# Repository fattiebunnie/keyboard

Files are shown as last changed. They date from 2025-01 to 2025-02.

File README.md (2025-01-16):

# Keyboard project 

This repo contains packages from different other repos so it will be easier to create a keyboard. 

## Keyboard 65 

65% keyboard

## Reference 

[tmk's keyboard_parts](https://github.com/tmk/keyboard_parts.pretty)

[tmk's kicad_lib](https://github.com/tmk/kicad_lib_tmk)

[egladman's keebs](https://github.com/egladman/keebs.pretty)

[mintexists' whiteboard](https://github.com/mintexists/WhiteBoard/tree/main)

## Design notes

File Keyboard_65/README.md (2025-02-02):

# Design was taken from [WhiteBoard by mintexists](https://github.com/mintexists/WhiteBoard/tree/main)

## Keyboard form factor

This keyboard is a 65% Keyboard with a knob and place for 2 screens to go onto 

### 3D model of the keyboard parts 

#### Top Plate
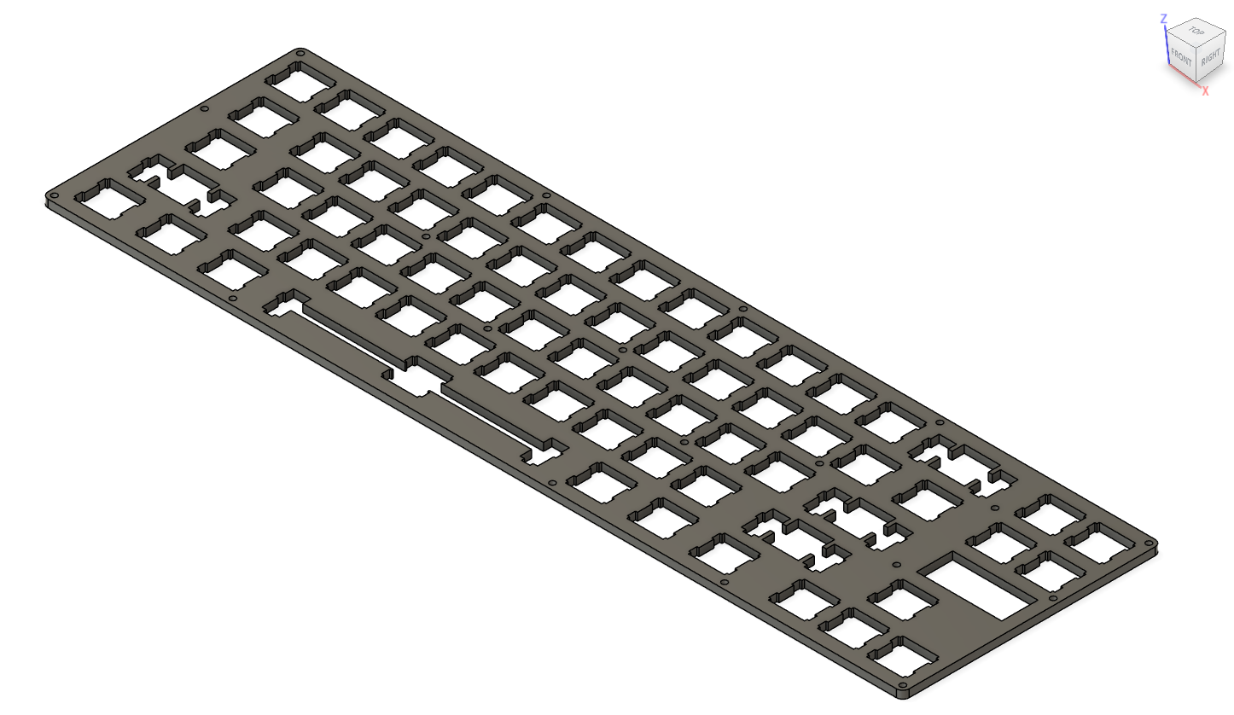
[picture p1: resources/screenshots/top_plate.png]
top_plate

#### Bot Plate
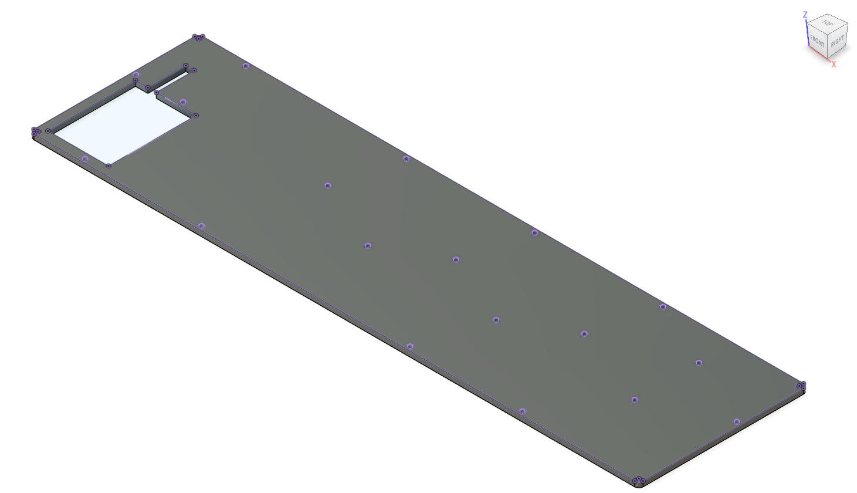
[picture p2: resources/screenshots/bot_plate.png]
bot_plate

#### PCB
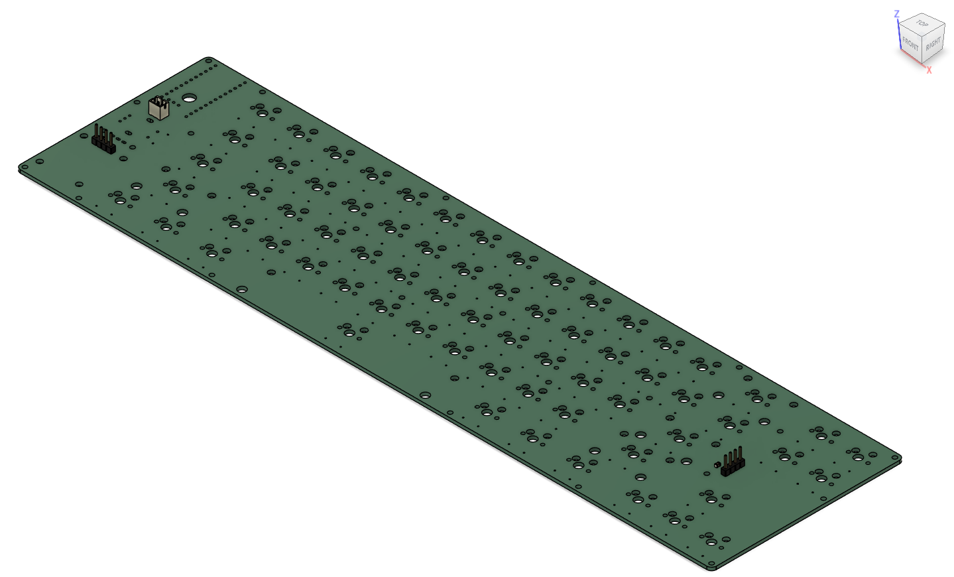
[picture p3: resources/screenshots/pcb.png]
PCB

#### Assembly
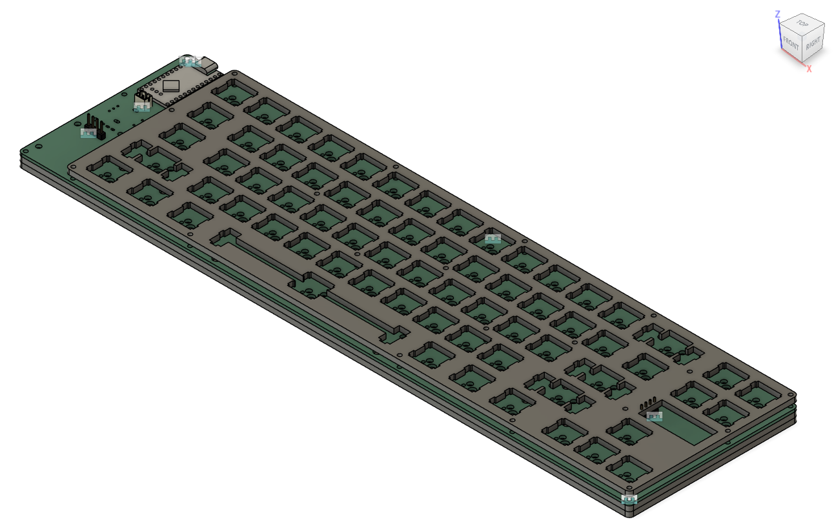
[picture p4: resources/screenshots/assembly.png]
assembly


## Tools

### Kayboard Layout Editor 

[Keyboard layout editor](https://www.keyboard-layout-editor.com/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'&_w:2.25%3B&=Enter%3B&@_w:2.25%3B&=Shift&=Z&=X&=C&=V&=B&=N&=M&=%3C%0A,&=%3E%0A.&=%3F%0A%2F%2F&_w:2.75%3B&=Shift&_x:0.25%3B&=%E2%86%91%3B&@_w:1.25%3B&=Ctrl&_w:1.25%3B&=Win&_w:1.25%3B&=Alt&_a:7&w:6.25%3B&=&_a:4&w:1.25%3B&=Alt&_w:1.25%3B&=Ctrl&_w:1.25%3B&=Menu&_x:0.5%3B&=%E2%86%90&=%E2%86%93&=%E2%86%92) is used for the holes for top plate. Though it may be unnecessary but aesthetics ig.

### Builder

[builder](http://builder.swillkb.com/) for the mounting holes. Copying the layout and adding pasting it into builder gives u the generated mounting holes.

### SVG2ShenZhen

[Badgeek's SVG to ShenZhen](https://github.com/badgeek/svg2shenzhen) makes svg into components in kicad.

### ZMK Firmware

ZMK Firmware was being used because it supported both bluetooth and I2C for display. 

# Complete build

Soldering Job: 

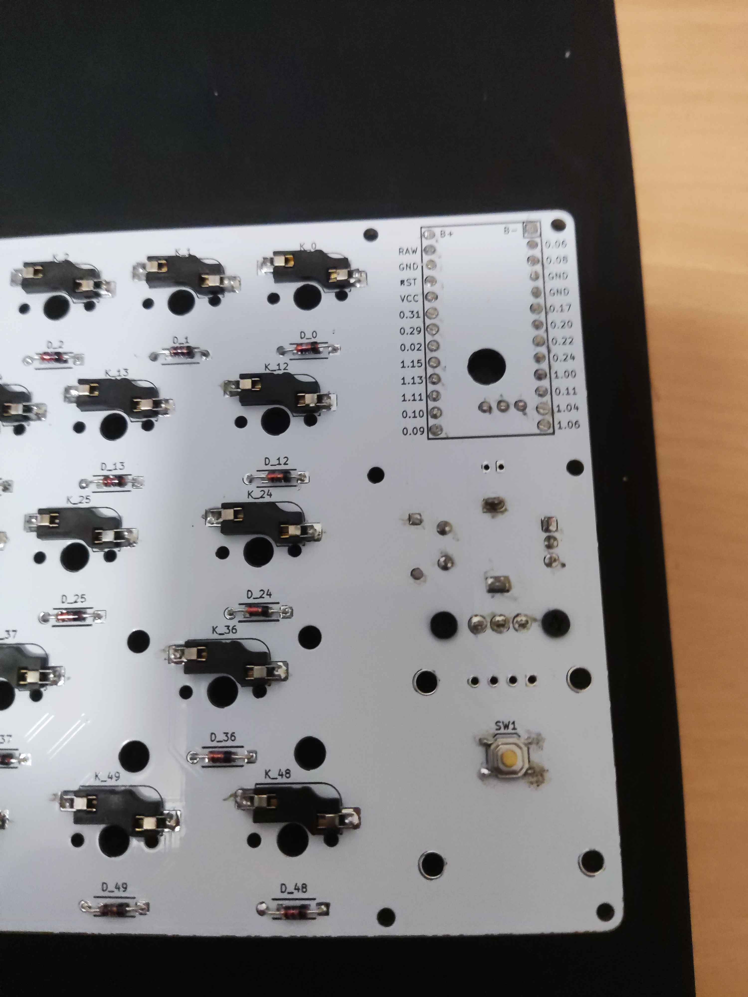
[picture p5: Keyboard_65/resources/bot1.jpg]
bot1


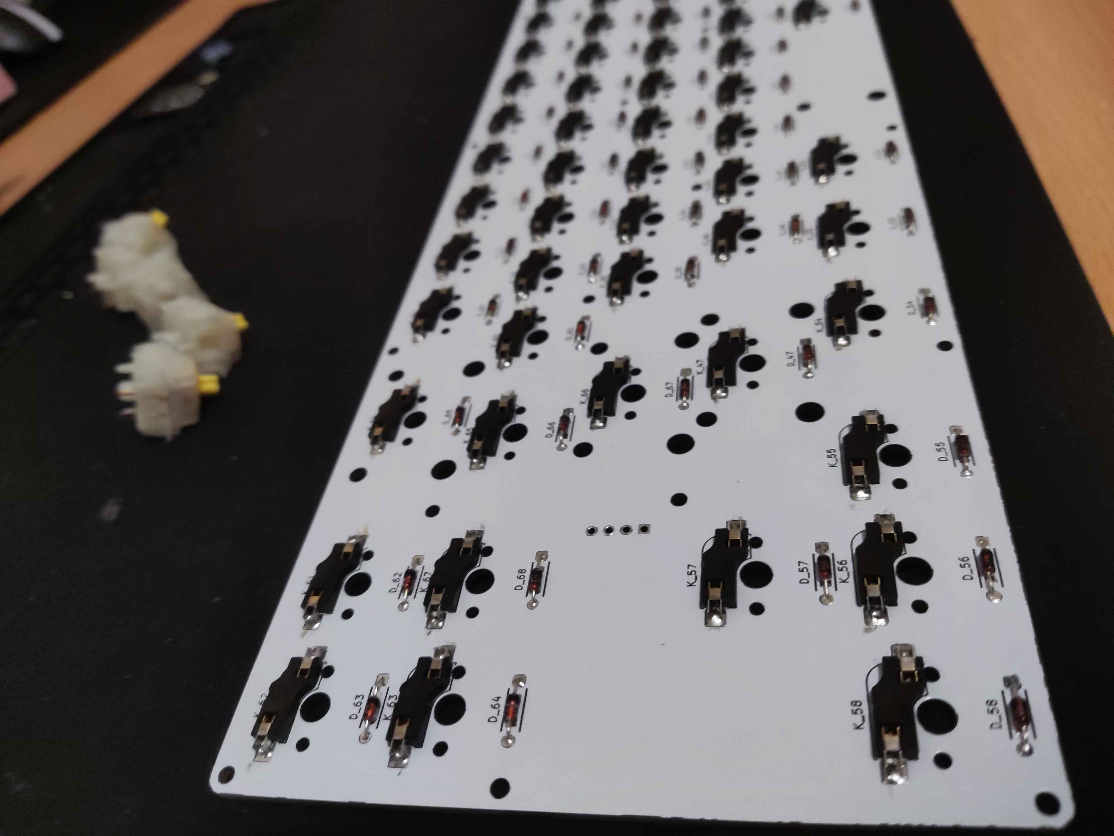
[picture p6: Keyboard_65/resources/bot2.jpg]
bot2


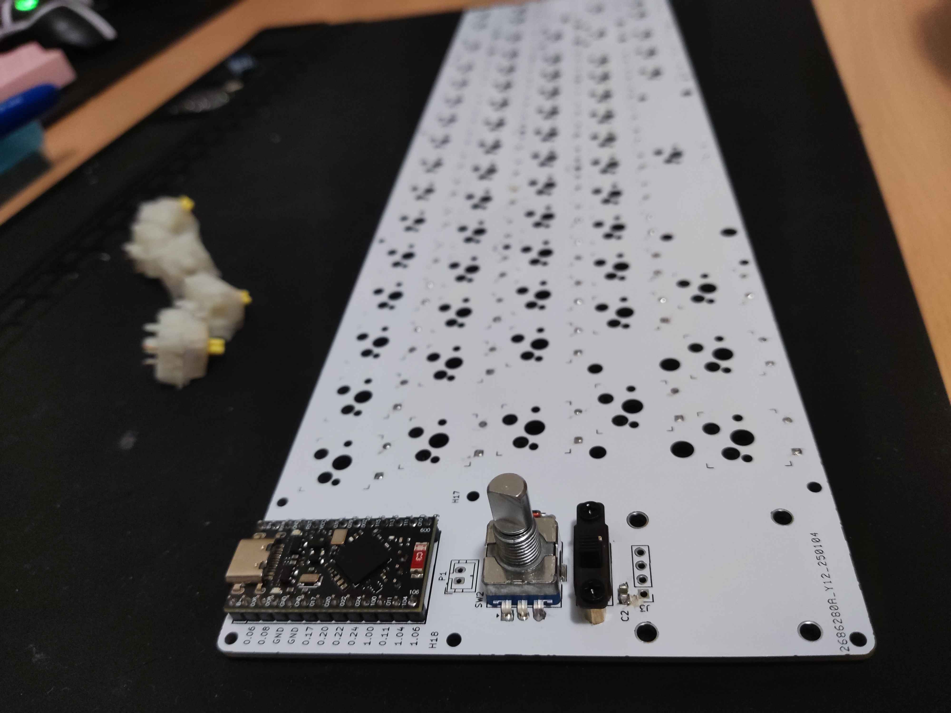
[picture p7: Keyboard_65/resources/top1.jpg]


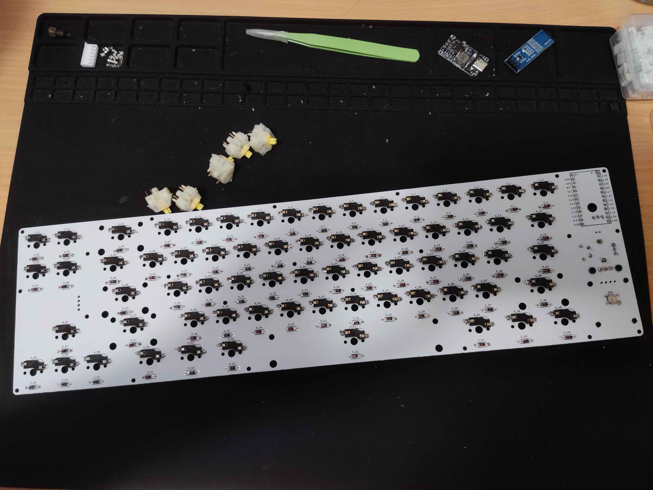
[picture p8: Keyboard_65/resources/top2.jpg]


I soldered the pins and then snipped the excess pins off together with some solder so it is as flush as possible and does not leave excess pointy edges that will end up scratching the user (possibly just me idk) in the future.

Build:

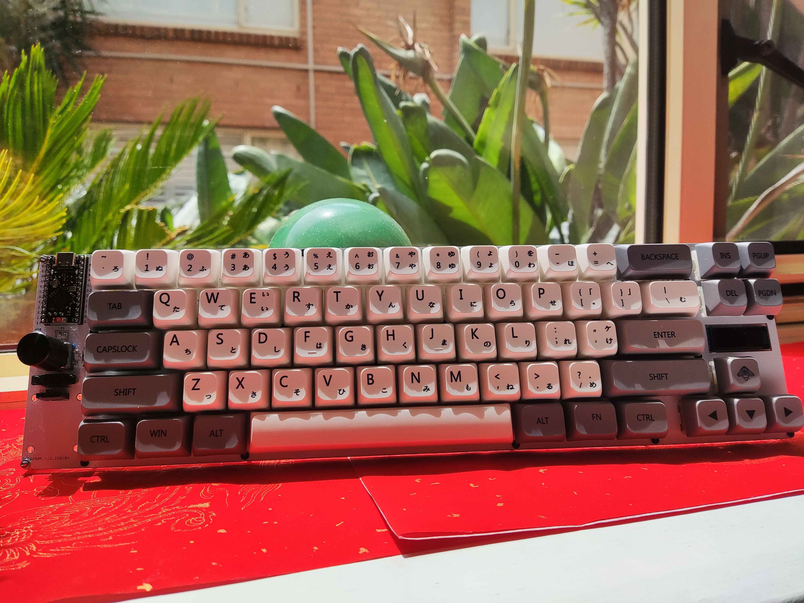
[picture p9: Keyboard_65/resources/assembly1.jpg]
assembly1


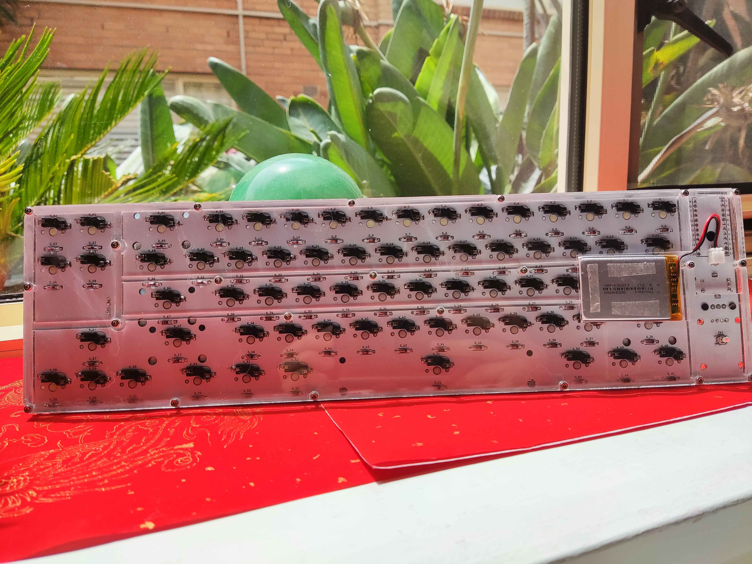
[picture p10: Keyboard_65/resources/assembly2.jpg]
assembly2


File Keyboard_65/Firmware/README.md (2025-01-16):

# Firmware

ZMK for bluetooth + battery management.

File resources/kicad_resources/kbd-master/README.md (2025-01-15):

# KBD - for building keyboard libraries

## KiCad Footprint Libraries

This repository contains the KiCad footprint libraries for building keyboard.

**The libraries in this repository are intended to be used with KiCad version 5 or with a nightly that supports rounded rectangle and polygon pads.**

Each footprint library is stored as a directory with the `.pretty` suffix. The footprint files are `.kicad_mod` files within 

## KiCad Symbols

This repository contains the KiCad schematic symbol libraries for building keyboard.

**The libraries in this repositiory are intended for KiCad version 5.x**

Each symbol library is stored as a `.lib` and `.dcm` file pair.

## KiCad 3D Models
This repository contains 3D models for rendering and MCAD integration, for use with [KiCAD EDA](http://kicad-pcb.org/) software.
The model needs a mechanical model source (a manually-modelled or script-generated file); its WRL counterpart file must be obtained as a conversion from the MCAD model

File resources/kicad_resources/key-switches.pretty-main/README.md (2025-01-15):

# Key Switches

[:globe_with_meridians:中文](/readme_zh-TW.md)

This is a [KiCad](https://www.kicad.org/) footprint library of mechanical keyboard switches, released under the [CERN-OHL-P v2](/LICENSE).

## Usage

It is recommended to use this library with [KiCAD KLE Placer](https://github.com/zykrah/kicad-kle-placer) or [kicad-kbplacer](https://github.com/adamws/kicad-kbplacer) for automatic switch placement.

If you're using Git, you can include this library as a [submodule](https://git-scm.com/docs/git-submodule) via `git submodule add https://github.com/siderakb/key-switches.pretty.git`

Keyboards created using this library: [ErgoSNM](https://github.com/siderakb/ergo-snm-keyboard), [Calcite](https://github.com/siderakb/calcite), [MS60](https://github.com/siderakb/ms60).

## Compatibility Table

| Preview [^preview] | Footprint [^sw-prefix] | Cherry MX | Cherry MX Low Profile | TTC KS32 |  Kailh Choc V1 [^k-choc1] |  Kailh Choc V2 [^k-choc2]  | Gateron Low Profile [^g-lp] | THT [^tht] | Hot-Swap | *nSilk* variants [^ns-suffix] | *swap* variants [^swap-suffix] |
| :---: | --- | :---: | :---: | :---: | :---: | :---: | :---: | :---: | :---: | :---: | :---: |
|  | MX_THT | :white_check_mark: | | | | | | :white_check_mark: | | :white_check_mark: | |
|  | MX_HotSwap_THT | :white_check_mark: | | | | | | :white_check_mark: | :white_check_mark: | :white_check_mark: | |
|  | MX_HotSwap_THT_double | :white_check_mark: | | | | | | :white_check_mark: | :white_check_mark: | | |
|  | MX_HotSwap_THT_double_alt1 | :white_check_mark: | | | | | | :white_check_mark: | :white_check_mark: | | |
|  | MX_HotSwap_THT_double_alt2 | :white_check_mark: | | | | | | :white_check_mark: | :white_check_mark: | | |
|  | MX_HotSwap_PTH | :white_check_mark: | | | | | | :bulb: [^pth] | :white_check_mark: | :white_check_mark: | :white_check_mark: |
|  | MX_HotSwap_PTH_double | :white_check_mark: | | | | | | :bulb: [^pth] | :white_check_mark: | | |
|  | MX_LowProfile_THT | |  :white_check_mark: | :bulb: [^t-ks_vs_c-mxlp] | | | | :white_check_mark: | | :white_check_mark: | |
|  | Gateron_LowProfile_THT | | | | | | :white_check_mark: | :white_check_mark: | | | |
|  | Gateron_LowProfile_HotSwap_THT | | | | | | :white_check_mark: | :white_check_mark: | :white_check_mark: | | |
|  | Gateron_LowProfile_HotSwap_PTH | | | | | | :white_check_mark: | :bulb: [^pth] | :white_check_mark: | | |
|  | Kailh_Choc_V1_THT | | | | :white_check_mark: | | | :white_check_mark: | | :white_check_mark: | :white_check_mark: |
|  | Kailh_Choc_V1_THT_alt1 | | | | :white_check_mark: | | | :white_check_mark: | | | |
|  | Kailh_Choc_V1_HotSwap | | | | :white_check_mark: | | | | :white_check_mark: | :white_check_mark: | |
|  | Kailh_Choc_V1_HotSwap_THT | | | | :white_check_mark: | | | :white_check_mark: | :white_check_mark: | | |
|  | Kailh_Choc_V1_HotSwap_PTH | | | | :white_check_mark: | | | :bulb: [^pth] | :white_check_mark: | | |
|  | Kailh_Choc_V2_THT | | | | | :white_check_mark: | | :white_check_mark: | | :white_check_mark: | |
|  | Kailh_Choc_V1V2_THT_Hybrid | | | | :bulb:[^k-choc1_vs_k-choc2] | :white_check_mark: | | :white_check_mark: | | | |
|  | MX_Kailh_Choc_V1V2_THT_Hybrid | :bulb: [^c-mx_vs_k-choc2] | | | :bulb:[^k-choc1_vs_k-choc2] | :white_check_mark: | | :white_check_mark: | | | |
|  | MX_LowProfile_Kailh_Choc_V1V2_THT_Hybrid | |  :white_check_mark: | :bulb: [^t-ks_vs_c-mxlp] | :bulb:[^k-choc1_vs_k-choc2] | :bulb:[^k-choc2_vs_c-mxlp] | | :white_check_mark: | | | |

> :white_check_mark:: Compatible; :bulb:: Conditionally compatible; Blank: Not compatible.

[^preview]: Preview images are for reference only and may not be updated with the footprints.
[^tht]: THT means through-hole soldering.
[^pth]: PTH means the holes of the Hot-Swap socket are plated, and the switches can be soldered directly without using a socket. However, the soldering difficulty is higher compared to the standard THT edition.
[^k-choc1]: Kailh Choc V1 also known as PG1350.
[^k-choc2]: Kailh Choc V2 also known as PG1353.
[^g-lp]: Gateron Low Profile 1.0 (aka KS-27) and 2.0 (aka KS-33) footprint are compatible.
[^t-ks_vs_c-mxlp]: TTC KS32 and Cherry MX Low Profile are very similar, basically compatible.
[^k-choc1_vs_k-choc2]: The center fix pin of Choc V1 is smaller than Choc V2, however Choc V1 has two additional fix pins ensuring its stability.
[^k-choc2_vs_c-mxlp]: The center fix pin of Choc V2 is smaller than Cherry MX Low Profile, Choc V2 may not be securely fastened.
[^c-mx_vs_k-choc2]: The center fix pin of Cherry MX is smaller than Choc V2, however some Cherry MX has two additional fix pins ensuring its stability.
[^sw-prefix]: Omit the "SW" prefix from the footprint name.
[^ns-suffix]: The footprint with "nSilk" suffix means no top layer silkscreen.
[^swap-suffix]: The footprint with "swap" suffix means the pin number swap.

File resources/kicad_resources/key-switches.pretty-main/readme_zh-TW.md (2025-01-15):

# Key Switches

[:globe_with_meridians:English](/README.md)

此為機械鍵盤鍵軸的 [KiCad](https://www.kicad.org/) Footprint 庫，以 [CERN-OHL-P v2 授權許可](/LICENSE)發佈。

## 用法

建議搭配 [KiCAD KLE Placer](https://github.com/zykrah/kicad-kle-placer) 或 [kicad-kbplacer](https://github.com/adamws/kicad-kbplacer) 使用本庫，以自動擺放鍵軸。

如果你在使用 Git，你可以將本庫作爲 [submodule](https://git-scm.com/docs/git-submodule) 使用，指令爲：`git submodule add https://github.com/siderakb/key-switches.pretty.git`

使用本庫所製作的鍵盤：[ErgoSNM](https://github.com/siderakb/ergo-snm-keyboard)、[Calcite](https://github.com/siderakb/calcite)、[MS60](https://github.com/siderakb/ms60)。

## 兼容表

| 預覽 [^preview] | Footprint [^sw-prefix] | Cherry MX | Cherry MX Low Profile | TTC KS32 |  Kailh Choc V1 [^k-choc1] |  Kailh Choc V2 [^k-choc2]  | Gateron Low Profile [^g-lp] | THT [^tht] | 熱插拔 | *nSilk* 變體 [^ns-suffix] | *swap* 變體 [^swap-suffix] |
| :---: | --- | :---: | :---: | :---: | :---: | :---: | :---: | :---: | :---: | :---: | :---: |
|  | MX_THT | :white_check_mark: | | | | | | :white_check_mark: | | :white_check_mark: | |
|  | MX_HotSwap_THT | :white_check_mark: | | | | | | :white_check_mark: | :white_check_mark: | :white_check_mark: | |
|  | MX_HotSwap_THT_double | :white_check_mark: | | | | | | :white_check_mark: | :white_check_mark: | | |
|  | MX_HotSwap_THT_double_alt1 | :white_check_mark: | | | | | | :white_check_mark: | :white_check_mark: | | |
|  | MX_HotSwap_THT_double_alt2 | :white_check_mark: | | | | | | :white_check_mark: | :white_check_mark: | | |
|  | MX_HotSwap_PTH | :white_check_mark: | | | | | | :bulb: [^pth] | :white_check_mark: | :white_check_mark: | :white_check_mark: |
|  | MX_HotSwap_PTH_double | :white_check_mark: | | | | | | :bulb: [^pth] | :white_check_mark: | | |
|  | MX_LowProfile_THT | |  :white_check_mark: | :bulb: [^t-ks_vs_c-mxlp] | | | | :white_check_mark: | | :white_check_mark: | |
|  | Gateron_LowProfile_THT | | | | | | :white_check_mark: | :white_check_mark: | | | |
|  | Gateron_LowProfile_HotSwap_THT | | | | | | :white_check_mark: | :white_check_mark: | :white_check_mark: | | |
|  | Gateron_LowProfile_HotSwap_PTH | | | | | | :white_check_mark: | :bulb: [^pth] | :white_check_mark: | | |
|  | Kailh_Choc_V1_THT | | | | :white_check_mark: | | | :white_check_mark: | | :white_check_mark: | :white_check_mark: |
|  | Kailh_Choc_V1_THT_alt1 | | | | :white_check_mark: | | | :white_check_mark: | | | |
|  | Kailh_Choc_V1_HotSwap | | | | :white_check_mark: | | | | :white_check_mark: | :white_check_mark: | |
|  | Kailh_Choc_V1_HotSwap_THT | | | | :white_check_mark: | | | :white_check_mark: | :white_check_mark: | | |
|  | Kailh_Choc_V1_HotSwap_PTH | | | | :white_check_mark: | | | :bulb: [^pth] | :white_check_mark: | | |
|  | Kailh_Choc_V2_THT | | | | | :white_check_mark: | | :white_check_mark: | | :white_check_mark: | |
|  | Kailh_Choc_V1V2_THT_Hybrid | | | | :bulb:[^k-choc1_vs_k-choc2] | :white_check_mark: | | :white_check_mark: | | | |
|  | MX_Kailh_Choc_V1V2_THT_Hybrid | :bulb: [^c-mx_vs_k-choc2] | | | :bulb:[^k-choc1_vs_k-choc2] | :white_check_mark: | | :white_check_mark: | | | |
|  | MX_LowProfile_Kailh_Choc_V1V2_THT_Hybrid | |  :white_check_mark: | :bulb: [^t-ks_vs_c-mxlp] | :bulb:[^k-choc1_vs_k-choc2] | :bulb:[^k-choc2_vs_c-mxlp] | | :white_check_mark: | | | |

> :white_check_mark:: 兼容; :bulb:: 有條件的兼容; 空白: 不兼容.

[^preview]: 預覽圖片僅供參考，不一定會隨 Footprint 更新。
[^tht]: THT 代表通孔焊接。
[^pth]: PTH 代表熱插拔座的孔壁有電鍍，鍵軸也可以在無熱插拔座的情況下直接焊接，但是其焊接難度會比標準 THT 版本更高。
[^k-choc1]: Kailh Choc V1 也稱為 PG1350。
[^k-choc2]: Kailh Choc V2 也稱為 PG1353。
[^g-lp]: Gateron Low Profile  1.0（又名 KS-27）與 2.0（又名 KS-33）的 Footprint 互相兼容。
[^t-ks_vs_c-mxlp]: TTC KS32 與 Cherry MX Low Profile 非常相似，基本上兼容。
[^k-choc1_vs_k-choc2]: Choc V1 的中央固定銷比 Choc V2 還小，但是 Choc V1 有另外兩個固定銷，所以足夠穩定。
[^k-choc2_vs_c-mxlp]: Choc V2 的中央固定銷比 Cherry MX Low Profile 還小，Choc V2 可能無法固定得很穩。
[^c-mx_vs_k-choc2]: Cherry MX 的中央固定銷比 Choc V2 還小，但是有些 Cherry MX 有另外兩個固定銷，所以足夠穩定。
[^sw-prefix]: 省略 Footprint 名稱中的 "SW" 前綴。
[^ns-suffix]: 帶有 "nSilk" 後綴的 Footprint 代表沒有頂層絲印。
[^swap-suffix]: 帶有 "swap" 後綴的 Footprint 代表接腳編號互換。

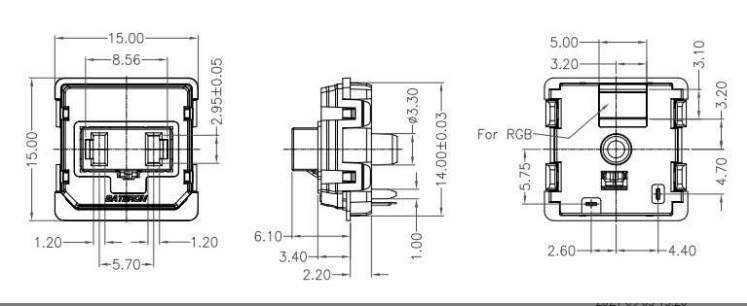
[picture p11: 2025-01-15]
resources/documentations/d513c566a904f95f54a6149d5275fb9d.jpg

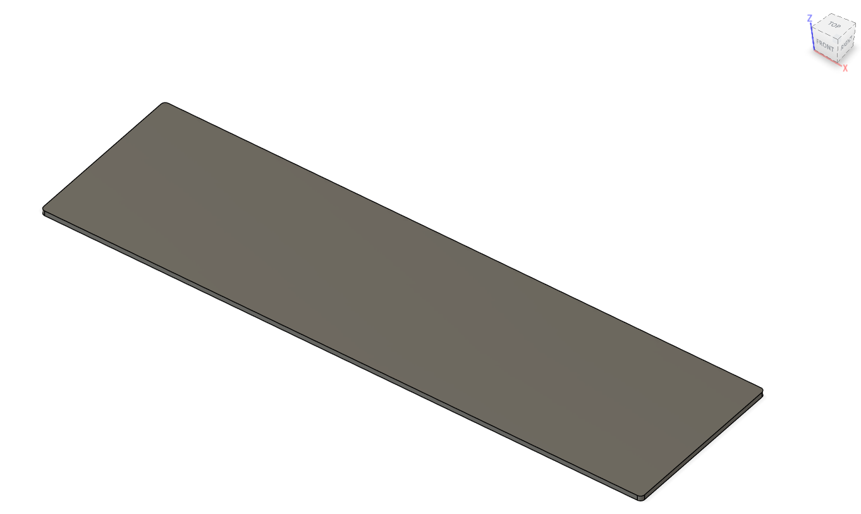
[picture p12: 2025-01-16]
resources/screenshots/bot.png

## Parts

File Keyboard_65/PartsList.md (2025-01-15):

# Parts List

| Name | Count | Comment | Cost | Recommended |
|---|---|---|---|---|
| PCB | 1 | Many sites have minimum order quantities larger then 1 | $14.30 | JLCPCB |
| Plate | 1 | Many sites have minimum order quantities larger then 1 | $30.00 | JLCPCB |
| Bottom Plate | 1 | Many sites have minimum order quantities larger then 1 | $15.80 | JLCPCB |
| Pro Micro Compatible Microcontroller | 1 | I recommend the Elite-C by Keebio **Make sure you order a set with header pins if you are not using a socket** | $18 | https://keeb.io/products/elite-c-low-profile-version-usb-c-pro-micro-replacement-atmega32u4 |
| Diodes | 60 | Get more to be safe | $2.99 | https://keeb.io/products/1n4148-diodes |
| Hot Swap Sockets | 60 | Get more to be safe | $10 for 100 | https://kbdfans.com/products/mechanical-keyboard-switches-kailh-pcb-socket |
| M2 Screws | 100 | This is more then needed but good to be safe | | |
| M2 Standoffs | | Needs to be heights with a difference of 5mm, for example 5mm and 10mm or 3mm and 8mm<br>(Make sure the screws aren't too long in case of short standoffs) | | |
| Rotary Encoder | 1 | Make sure this is high quality as low quality encoders can have issues | $2 | https://keeb.io/products/rotary-encoder-ec11 |
| Encoder Knob | 1 | You can find cheaper knobs on Keebio but I prefer these | $15.99 | https://www.amazon.com/dp/B071DTQ2WN |
| Switches | 60 | | | |
| Keycaps | 60 | I recommend a set of uniform profile keycaps or a set of keycaps compatible with the Preonic | | |
| Plate Mount 2u Stabilizer | 1 | Currently this is not compatible with PCB mount stabilizers but this can be fixed if needed | | |
| (Optional) Microcontroller Sockets | 1 | Use these if you want the ability to change out what microcontroller you use | $4-$10 | |
| (Optional) 6mm Tactile Button | 1 | This is used as a reset button | | |
| (Optional) Braided USB Cable | 1 | Recommending Donut Cables here because they helped me out with learning some PCB design (I was not paid to say this) | $10-$20 | https://donutcables.com/ |

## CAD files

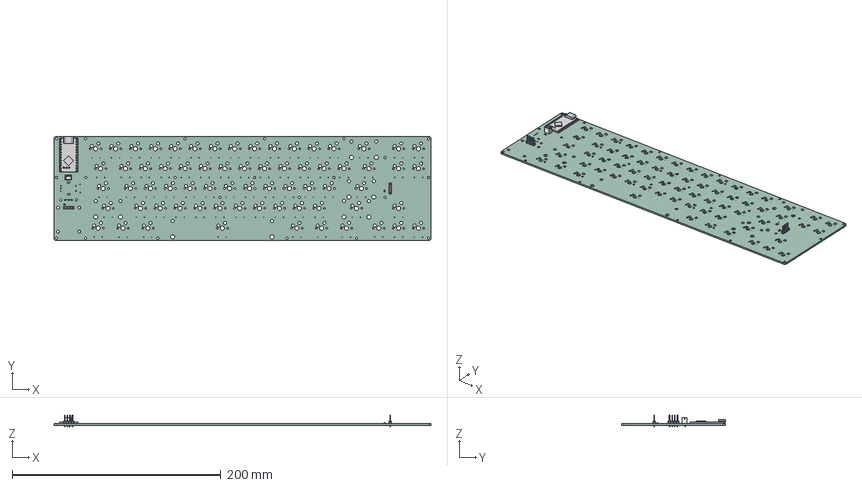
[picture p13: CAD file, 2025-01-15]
Keyboard_65/Kicad Files/Mainpcb.step
361.6 x 100.2 x 11.9 mm
JST_B2B_PH_K
C_0805_2012Metric x 2
nrf54840-ProMicro v2
PinHeader_1x04_P254mm_Vertical x 2
Mainpcb_PCB

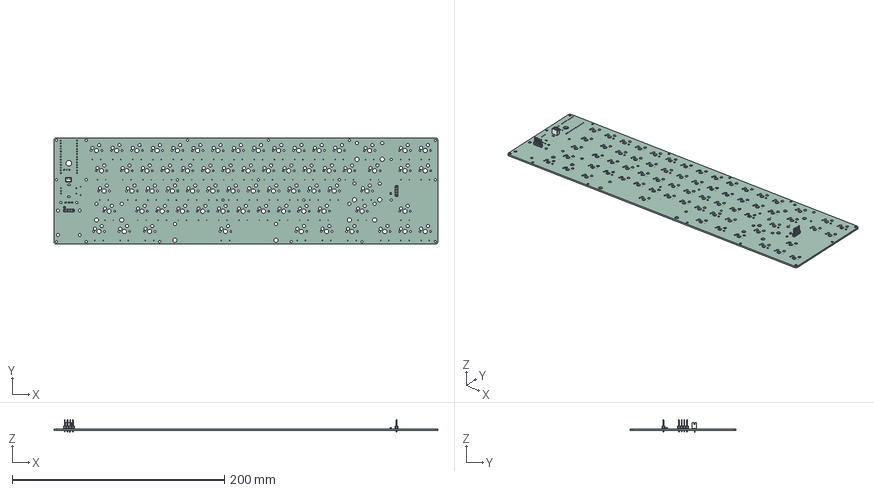
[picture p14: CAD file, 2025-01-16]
resources/3DModels/Mainpcb v2.step
361.6 x 100.2 x 11.9 mm
JST_B2B_PH_K
C_0805_2012Metric_1 x 2
PinHeader_1x04_P254mm_Vertical x 2
Mainpcb_PCB

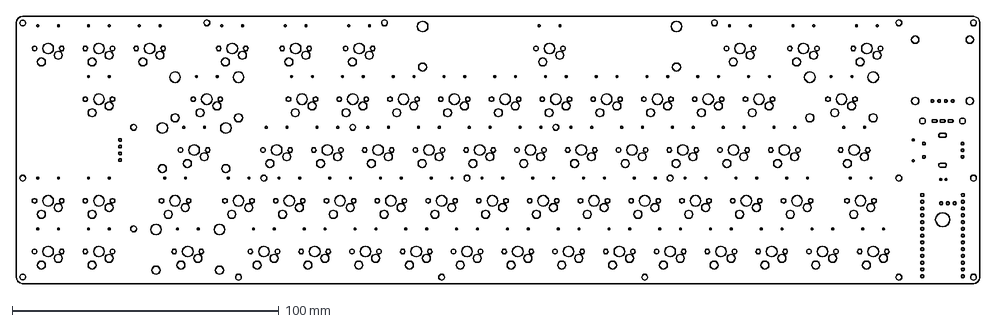
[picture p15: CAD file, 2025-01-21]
Keyboard_65/kb_layout.dxf
361.6 x 100.2 mm

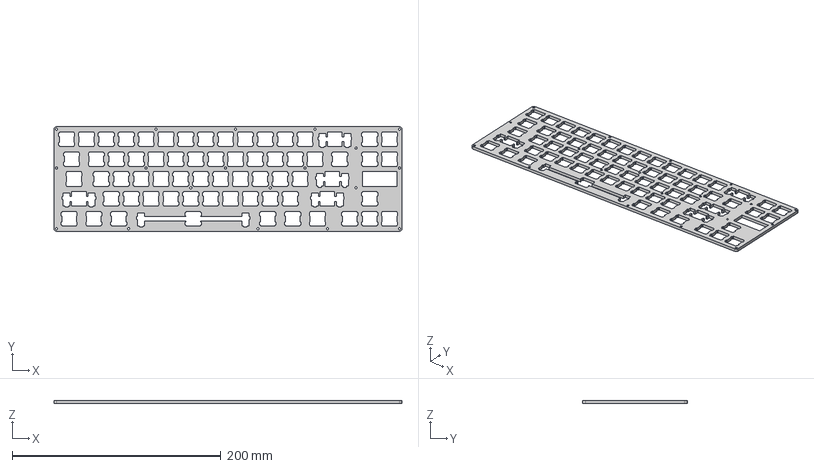
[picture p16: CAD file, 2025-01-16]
resources/3DModels/top_layout v3.step
333.6 x 100.2 x 3.00 mm

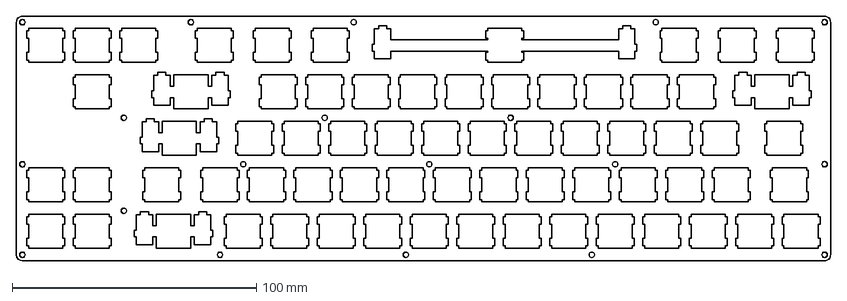
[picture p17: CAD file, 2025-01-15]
resources/misc/top_v2.dxf
333.6 x 100.2 mm

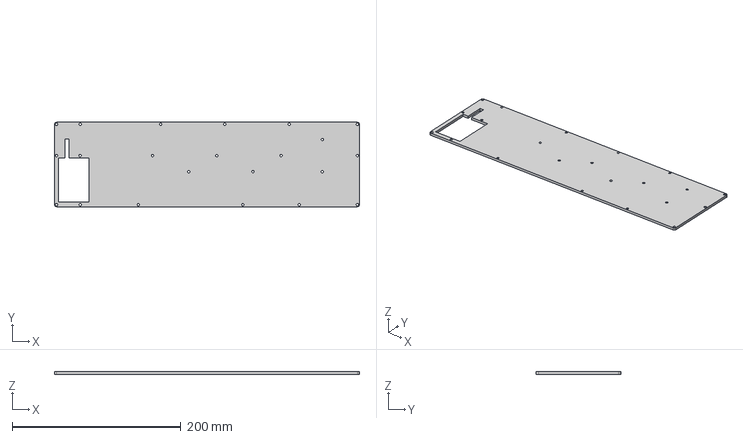
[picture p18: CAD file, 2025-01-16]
resources/3DModels/kb_bot_plate v4.step
361.6 x 100.2 x 3.00 mm

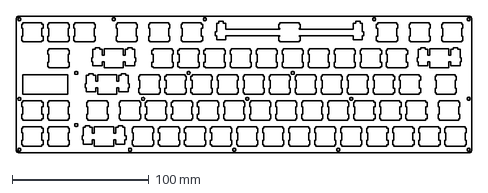
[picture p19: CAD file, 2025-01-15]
resources/misc/top_plate_v2.dxf
333.6 x 100.2 mm

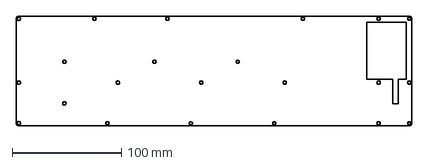
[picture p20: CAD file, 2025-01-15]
resources/misc/bot_plate.dxf
361.6 x 100.2 mm

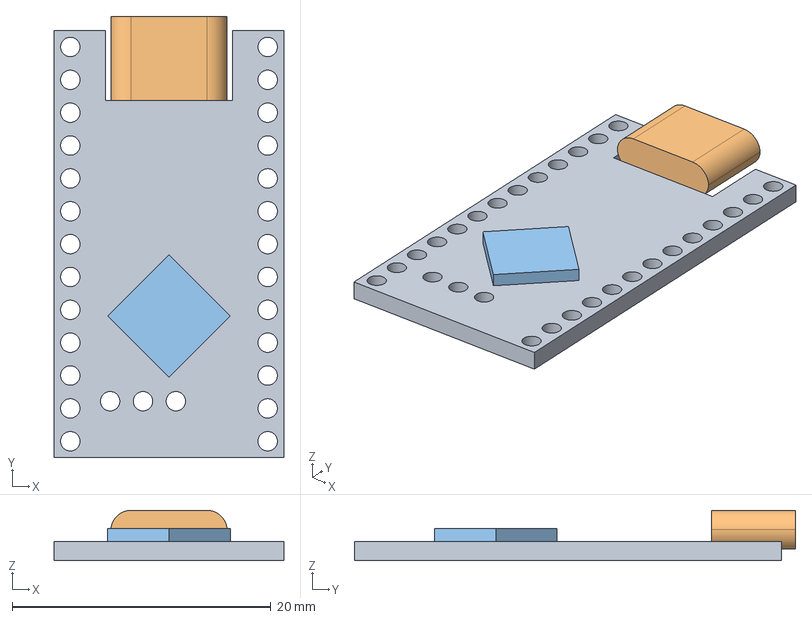
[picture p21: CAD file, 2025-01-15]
resources/3DModels/nrf54840-ProMicro.step
17.8 x 34.1 x 3.90 mm
board
usbc_port
mcu

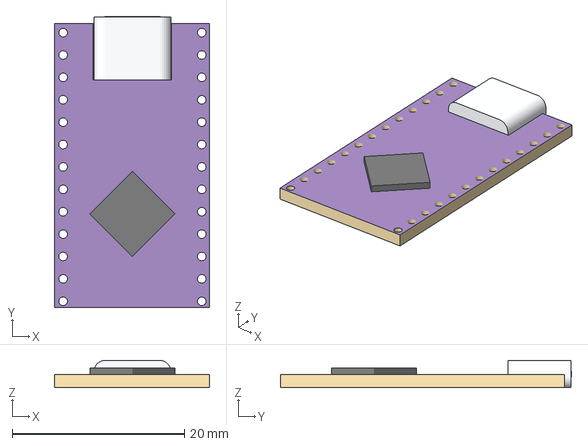
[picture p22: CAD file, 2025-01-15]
resources/3DModels/nRF52840 Reference.3mf
18.0 x 33.9 x 3.15 mm

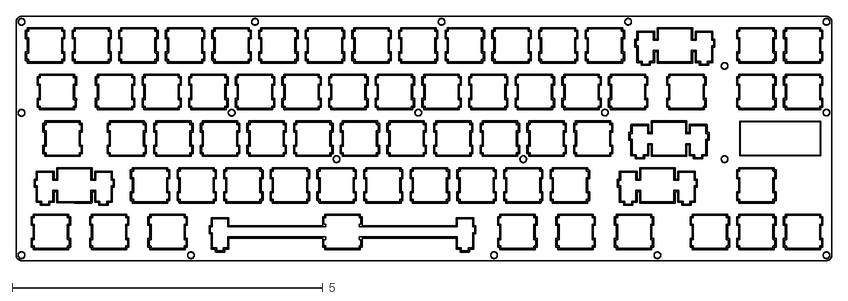
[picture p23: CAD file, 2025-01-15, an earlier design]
Keyboard_65/Kicad Files/Gerbers/archive/Top3/top-F_Cu.dxf
13.1 x 3.93

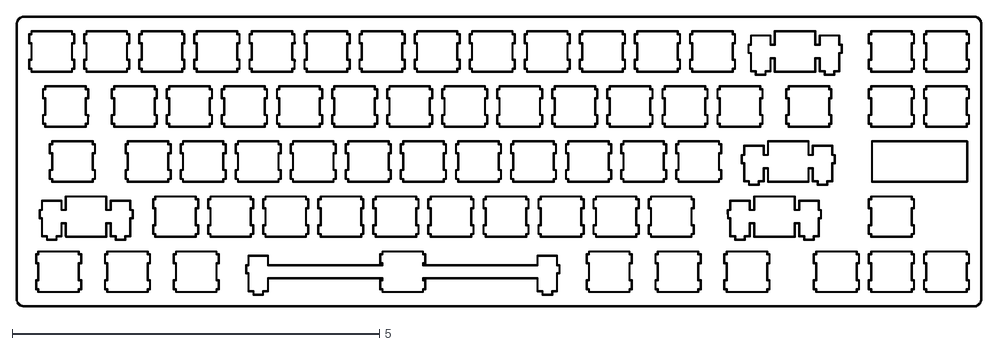
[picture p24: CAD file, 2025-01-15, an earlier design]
Keyboard_65/Kicad Files/Gerbers/archive/Top3/top-Edge_Cuts.dxf
13.1 x 3.96

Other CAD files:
Keyboard_65/Kicad Files/Gerbers/archive/Top3/top-F_Fab.dxf
Keyboard_65/Kicad Files/Gerbers/archive/Top3/top-B_Fab.dxf
Keyboard_65/Kicad Files/Gerbers/archive/Top3/top-B_Mask.dxf
Keyboard_65/Kicad Files/Gerbers/archive/Top3/top-B_Paste.dxf
Keyboard_65/Kicad Files/Gerbers/archive/Top3/top-B_Silkscreen.dxf
Keyboard_65/Kicad Files/Gerbers/archive/Top3/top-F_Mask.dxf
Keyboard_65/Kicad Files/Gerbers/archive/Top3/top-F_Paste.dxf
Keyboard_65/Kicad Files/Gerbers/archive/Top3/top-F_Silkscreen.dxf
resources/3DModels/Mainpcb v2.f3d
resources/3DModels/bot_plate_2.f3d
resources/3DModels/top_layout v3.f3d

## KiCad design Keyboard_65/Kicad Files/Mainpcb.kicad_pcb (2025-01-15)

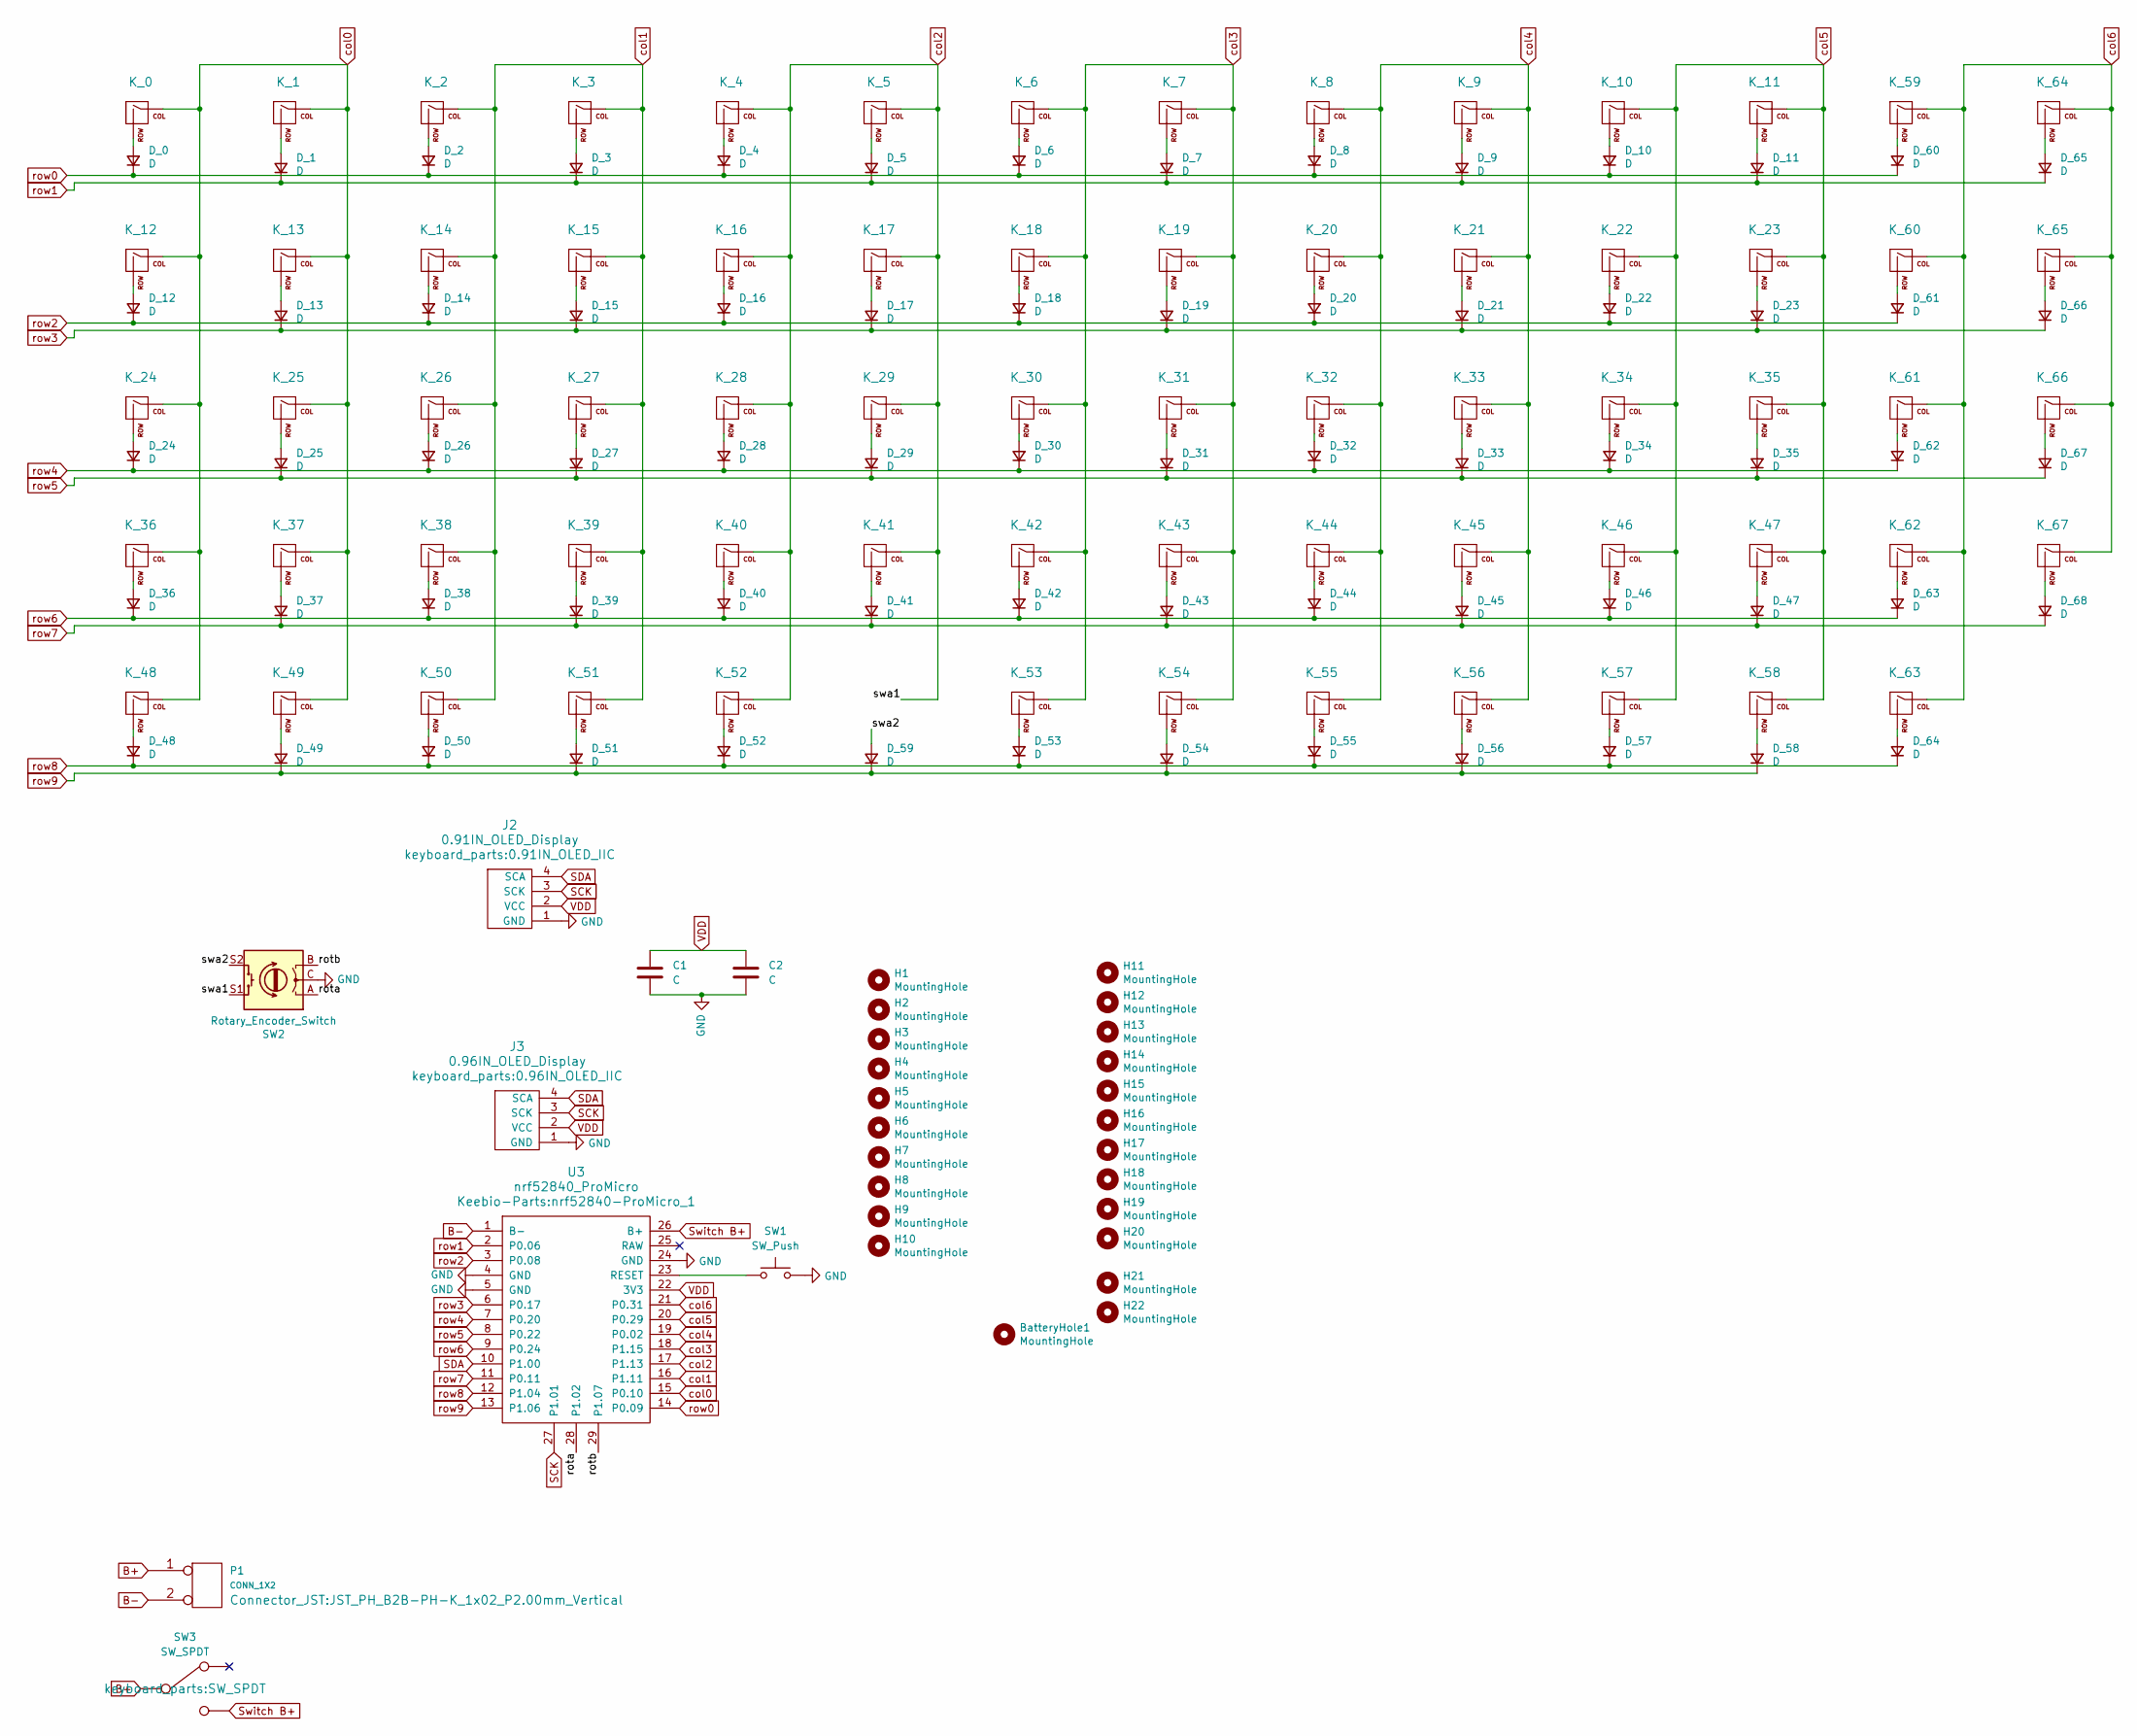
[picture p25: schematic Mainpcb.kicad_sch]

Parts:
BatteryHole1: MountingHole; MountingHole_5.3mm_M5
C1, C2: C; C_0805_2012Metric_Pad1.18x1.45mm_HandSolder
D_0, D_1, D_2, D_3, D_4, D_5, D_6, D_7, D_8, D_9, D_10, D_11, D_12, D_13, D_14, D_15, D_16, D_17, D_18, D_19, D_20, D_21, D_22, D_23, D_24, D_25, D_26, D_27, D_28, D_29, D_30, D_31, D_32, D_33, D_34, D_35, D_36, D_37, D_38, D_39, D_40, D_41, D_42, D_43, D_44, D_45, D_46, D_47, D_48, D_49, D_50, D_51, D_52, D_53, D_54, D_55, D_56, D_57, D_58, D_59, D_60, D_61, D_62, D_63, D_64, D_65, D_66, D_67, D_68: D; D_SOD123_axial
H1, H2, H3, H4, H5, H6, H7, H8, H9, H10, H11, H12, H13, H14, H15, H16, H17, H18, H19, H20, H21, H22: MountingHole; MountingHole_2.2mm_M2
J2: 0.91IN_OLED_Display; 0.91IN_OLED_IIC
J3: 0.96IN_OLED_Display; 0.96IN_OLED_IIC
K_0, K_1, K_2, K_3, K_4, K_5, K_6, K_7, K_8, K_9, K_10, K_11, K_12, K_13, K_14, K_15, K_16, K_17, K_18, K_19, K_20, K_21, K_22, K_23, K_24, K_25, K_26, K_27, K_28, K_29, K_30, K_31, K_32, K_33, K_34, K_35, K_36, K_37, K_38, K_39, K_40, K_41, K_42, K_43, K_44, K_45, K_46, K_47, K_48, K_49, K_50, K_51, K_52, K_53, K_54, K_55, K_56, K_57, K_58, K_59, K_60, K_61, K_62, K_63, K_64, K_65, K_66, K_67: KEYSW; Kailh_socket_MX
P1: CONN_1X2; JST_PH_B2B-PH-K_1x02_P2.00mm_Vertical
SW1: SW_Push; SW_Push_1P1T_XKB_TS-1187A
SW2: Rotary_Encoder_Switch; RotaryEncoder_Alps_EC11E-Switch_Vertical_H20mm_1
SW3: SW_SPDT
U3: nrf52840_ProMicro; nrf52840-ProMicro_1

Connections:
/rota: SW2.A, U3.28 (P1.02)
/rotb: SW2.B, U3.29 (P1.07)
/swa2: D_59.2 (A), SW2.S2
B+: P1.1, SW3.2
B-: P1.2, U3.1 (B-)
GND: C1.2, C2.2, J2.1 (GND), J3.1 (GND), SW1.2, SW2.C, U3.4 (GND), U3.5 (GND), U3.24 (GND)
unnamed: D_0.2 (A), K_0.2 (ROW)
unnamed: D_1.2 (A), K_1.2 (ROW)
unnamed: D_2.2 (A), K_2.2 (ROW)
unnamed: D_3.2 (A), K_3.2 (ROW)
unnamed: D_4.2 (A), K_4.2 (ROW)
unnamed: D_5.2 (A), K_5.2 (ROW)
unnamed: D_6.2 (A), K_6.2 (ROW)
unnamed: D_7.2 (A), K_7.2 (ROW)
unnamed: D_8.2 (A), K_8.2 (ROW)
unnamed: D_9.2 (A), K_9.2 (ROW)
unnamed: D_10.2 (A), K_10.2 (ROW)
unnamed: D_11.2 (A), K_11.2 (ROW)
unnamed: D_12.2 (A), K_12.2 (ROW)
unnamed: D_13.2 (A), K_13.2 (ROW)
unnamed: D_14.2 (A), K_14.2 (ROW)
unnamed: D_15.2 (A), K_15.2 (ROW)
unnamed: D_16.2 (A), K_16.2 (ROW)
unnamed: D_17.2 (A), K_17.2 (ROW)
unnamed: D_18.2 (A), K_18.2 (ROW)
unnamed: D_19.2 (A), K_19.2 (ROW)
unnamed: D_20.2 (A), K_20.2 (ROW)
unnamed: D_21.2 (A), K_21.2 (ROW)
unnamed: D_22.2 (A), K_22.2 (ROW)
unnamed: D_23.2 (A), K_23.2 (ROW)
unnamed: D_24.2 (A), K_24.2 (ROW)
unnamed: D_25.2 (A), K_25.2 (ROW)
unnamed: D_26.2 (A), K_26.2 (ROW)
unnamed: D_27.2 (A), K_27.2 (ROW)
unnamed: D_28.2 (A), K_28.2 (ROW)
unnamed: D_29.2 (A), K_29.2 (ROW)
unnamed: D_30.2 (A), K_30.2 (ROW)
unnamed: D_31.2 (A), K_31.2 (ROW)
unnamed: D_32.2 (A), K_32.2 (ROW)
unnamed: D_33.2 (A), K_33.2 (ROW)
unnamed: D_34.2 (A), K_34.2 (ROW)
unnamed: D_35.2 (A), K_35.2 (ROW)
unnamed: D_36.2 (A), K_36.2 (ROW)
unnamed: D_37.2 (A), K_37.2 (ROW)
unnamed: D_38.2 (A), K_38.2 (ROW)
unnamed: D_39.2 (A), K_39.2 (ROW)
unnamed: D_40.2 (A), K_40.2 (ROW)
unnamed: D_41.2 (A), K_41.2 (ROW)
unnamed: D_42.2 (A), K_42.2 (ROW)
unnamed: D_43.2 (A), K_43.2 (ROW)
unnamed: D_44.2 (A), K_44.2 (ROW)
unnamed: D_45.2 (A), K_45.2 (ROW)
unnamed: D_46.2 (A), K_46.2 (ROW)
unnamed: D_47.2 (A), K_47.2 (ROW)
unnamed: D_48.2 (A), K_48.2 (ROW)
unnamed: D_49.2 (A), K_49.2 (ROW)
unnamed: D_50.2 (A), K_50.2 (ROW)
unnamed: D_51.2 (A), K_51.2 (ROW)
unnamed: D_52.2 (A), K_52.2 (ROW)
unnamed: D_53.2 (A), K_53.2 (ROW)
unnamed: D_54.2 (A), K_54.2 (ROW)
unnamed: D_55.2 (A), K_55.2 (ROW)
unnamed: D_56.2 (A), K_56.2 (ROW)
unnamed: D_57.2 (A), K_57.2 (ROW)
unnamed: D_58.2 (A), K_58.2 (ROW)
unnamed: D_60.2 (A), K_59.2 (ROW)
unnamed: D_61.2 (A), K_60.2 (ROW)
unnamed: D_62.2 (A), K_61.2 (ROW)
unnamed: D_63.2 (A), K_62.2 (ROW)
unnamed: D_64.2 (A), K_63.2 (ROW)
unnamed: D_65.2 (A), K_64.2 (ROW)
unnamed: D_66.2 (A), K_65.2 (ROW)
unnamed: D_67.2 (A), K_66.2 (ROW)
unnamed: D_68.2 (A), K_67.2 (ROW)
unnamed: SW1.1, U3.23 (RESET)
SCK: J2.3 (SCK), J3.3 (SCK), U3.27 (P1.01)
SDA: J2.4 (SCA), J3.4 (SCA), U3.10 (P1.00)
Switch B+: SW3.3, U3.26 (B+)
VDD: C1.1, C2.1, J2.2 (VCC), J3.2 (VCC), U3.22 (3V3)
col0: K_0.1 (COL), K_1.1 (COL), K_12.1 (COL), K_13.1 (COL), K_24.1 (COL), K_25.1 (COL), K_36.1 (COL), K_37.1 (COL), K_48.1 (COL), K_49.1 (COL), U3.15 (P0.10)
col1: K_2.1 (COL), K_3.1 (COL), K_14.1 (COL), K_15.1 (COL), K_26.1 (COL), K_27.1 (COL), K_38.1 (COL), K_39.1 (COL), K_50.1 (COL), K_51.1 (COL), U3.16 (P1.11)
col2: K_4.1 (COL), K_5.1 (COL), K_16.1 (COL), K_17.1 (COL), K_28.1 (COL), K_29.1 (COL), K_40.1 (COL), K_41.1 (COL), K_52.1 (COL), SW2.S1, U3.17 (P1.13)
col3: K_6.1 (COL), K_7.1 (COL), K_18.1 (COL), K_19.1 (COL), K_30.1 (COL), K_31.1 (COL), K_42.1 (COL), K_43.1 (COL), K_53.1 (COL), K_54.1 (COL), U3.18 (P1.15)
col4: K_8.1 (COL), K_9.1 (COL), K_20.1 (COL), K_21.1 (COL), K_32.1 (COL), K_33.1 (COL), K_44.1 (COL), K_45.1 (COL), K_55.1 (COL), K_56.1 (COL), U3.19 (P0.02)
col5: K_10.1 (COL), K_11.1 (COL), K_22.1 (COL), K_23.1 (COL), K_34.1 (COL), K_35.1 (COL), K_46.1 (COL), K_47.1 (COL), K_57.1 (COL), K_58.1 (COL), U3.20 (P0.29)
col6: K_59.1 (COL), K_60.1 (COL), K_61.1 (COL), K_62.1 (COL), K_63.1 (COL), K_64.1 (COL), K_65.1 (COL), K_66.1 (COL), K_67.1 (COL), U3.21 (P0.31)
row0: D_0.1 (K), D_2.1 (K), D_4.1 (K), D_6.1 (K), D_8.1 (K), D_10.1 (K), D_60.1 (K), U3.14 (P0.09)
row1: D_1.1 (K), D_3.1 (K), D_5.1 (K), D_7.1 (K), D_9.1 (K), D_11.1 (K), D_65.1 (K), U3.2 (P0.06)
row2: D_12.1 (K), D_14.1 (K), D_16.1 (K), D_18.1 (K), D_20.1 (K), D_22.1 (K), D_61.1 (K), U3.3 (P0.08)
row3: D_13.1 (K), D_15.1 (K), D_17.1 (K), D_19.1 (K), D_21.1 (K), D_23.1 (K), D_66.1 (K), U3.6 (P0.17)
row4: D_24.1 (K), D_26.1 (K), D_28.1 (K), D_30.1 (K), D_32.1 (K), D_34.1 (K), D_62.1 (K), U3.7 (P0.20)
row5: D_25.1 (K), D_27.1 (K), D_29.1 (K), D_31.1 (K), D_33.1 (K), D_35.1 (K), D_67.1 (K), U3.8 (P0.22)
row6: D_36.1 (K), D_38.1 (K), D_40.1 (K), D_42.1 (K), D_44.1 (K), D_46.1 (K), D_63.1 (K), U3.9 (P0.24)
row7: D_37.1 (K), D_39.1 (K), D_41.1 (K), D_43.1 (K), D_45.1 (K), D_47.1 (K), D_68.1 (K), U3.11 (P0.11)
row8: D_48.1 (K), D_50.1 (K), D_52.1 (K), D_53.1 (K), D_55.1 (K), D_57.1 (K), D_64.1 (K), U3.12 (P1.04)
row9: D_49.1 (K), D_51.1 (K), D_54.1 (K), D_56.1 (K), D_58.1 (K), D_59.1 (K), U3.13 (P1.06)

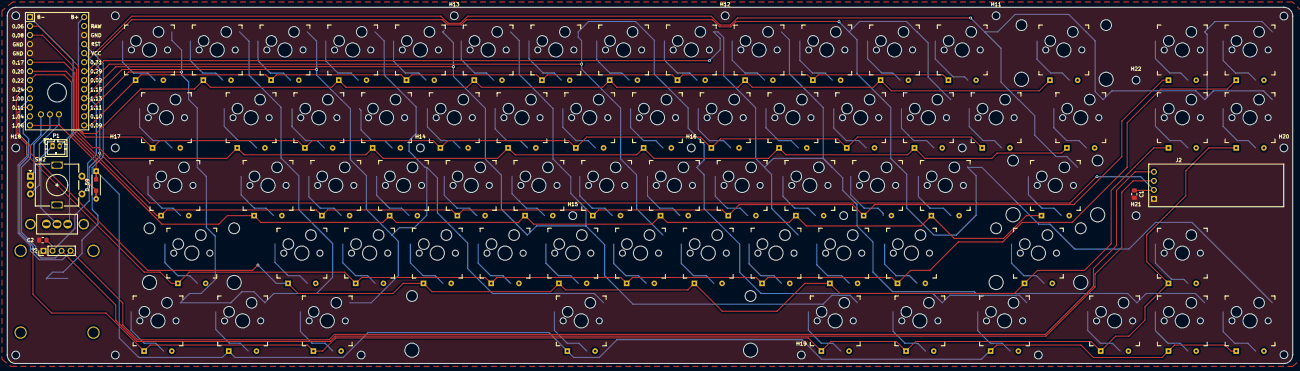
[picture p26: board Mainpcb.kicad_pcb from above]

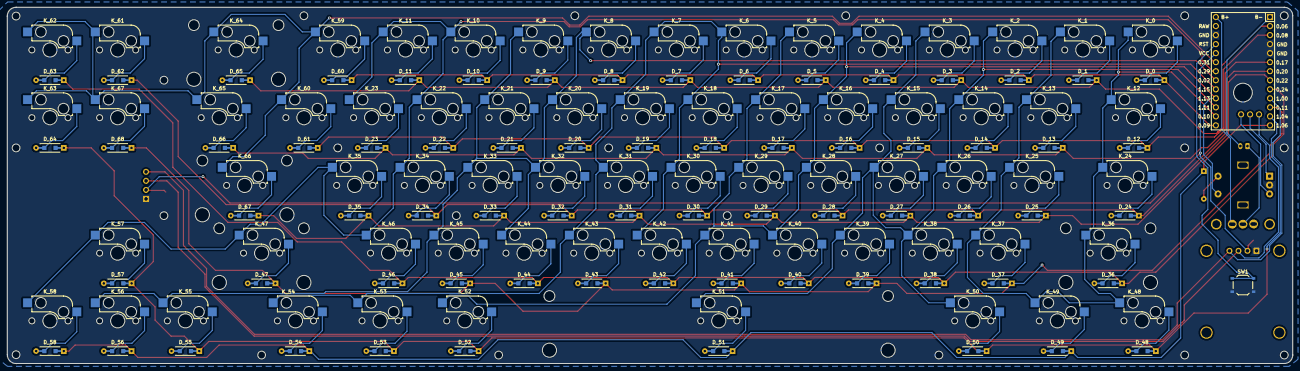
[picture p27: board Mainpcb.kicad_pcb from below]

Board: 2 copper layers, 361.6 x 100.2 mm, 169 parts (69 on the bottom side), 96 nets.

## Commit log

2025-01-21 added pictures of finished soldering job
    [kb_layout.dxf]
2025-02-02 added final assembly
